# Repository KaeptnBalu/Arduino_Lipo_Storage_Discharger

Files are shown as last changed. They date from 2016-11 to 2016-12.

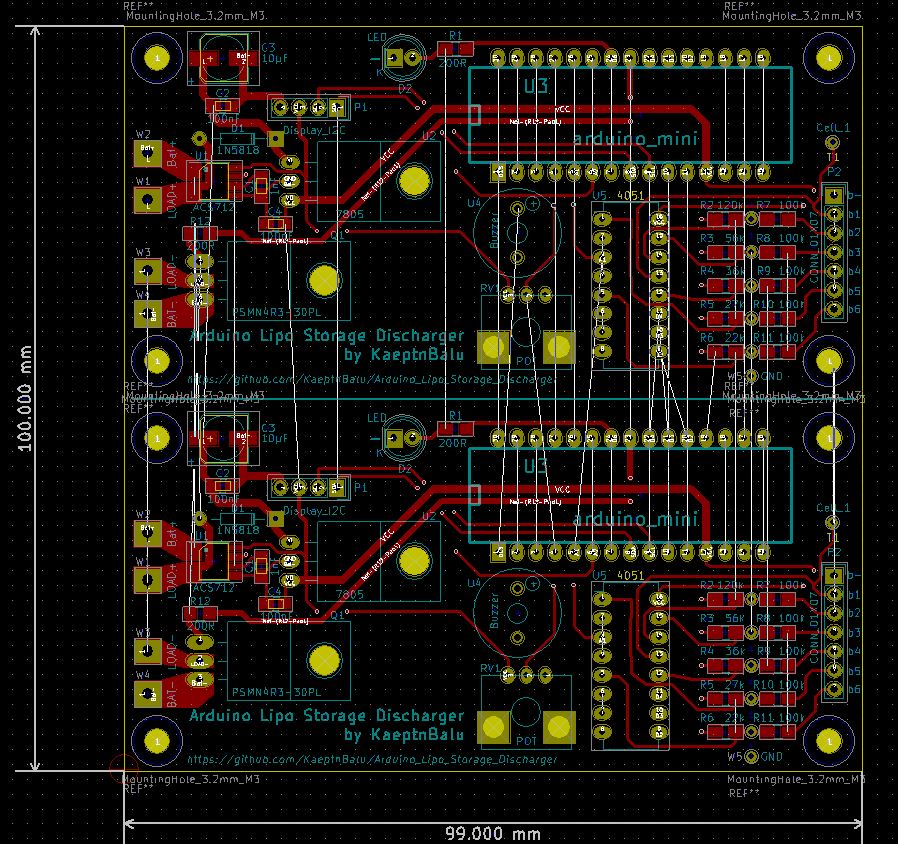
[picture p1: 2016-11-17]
PCB/PCBx2.JPG

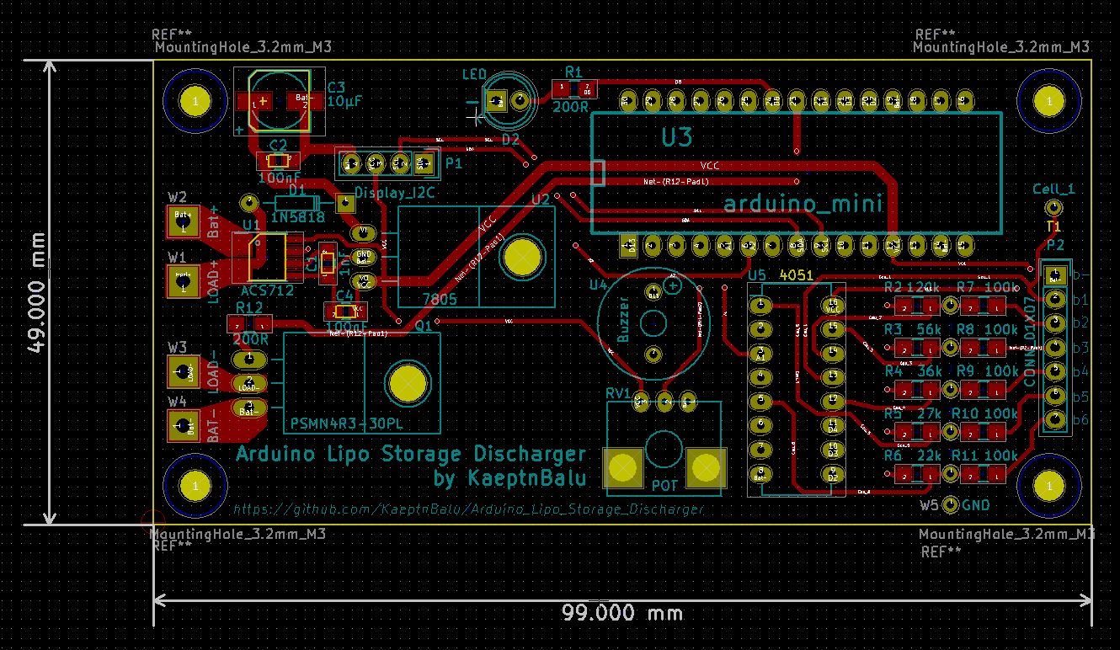
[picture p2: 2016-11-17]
PCB/PCB.JPG

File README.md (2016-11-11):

# Arduino_Lipo_Storage_Discharger
Arduino controlled lipo battery storage discharger with current measurement and current control.

This device can discharge lipo and liion batterys to storage voltage without external power supply.
It can handle 2-6s lipos (8.4 - 25.2V) and can draw up to about 10A continues. 
(Max 140W, with 4 light bulbs)
The current can be controlled by the potentiometer.

The oled display will show: 
- current in A
- battery voltage
- each cell voltage
- total discharged current in mAh
- discharge time

For the discharging load 4 pieces 12V 35w G4 halogen bulbs will be used.
When the storage voltage is reached it will disconnect the load and the buzzer will beep every few seconds.

If you forget to disconnect the Lipo battery after discharging and the voltage drops below 3.75V per cell 
it will go to a low power consumption mode and beep only every few minutes.

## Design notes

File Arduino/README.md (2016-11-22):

Attention: work in progress, code not completely finshed yet

Arduino Code for the Lipo Storage Discharger.

There are external librarys used:
- Ardafruit SSD1306 Library
https://github.com/adafruit/Adafruit_SSD1306
- Ardafruit GFX Library 
https://github.com/adafruit/Adafruit-GFX-Library
- PID Library 
https://github.com/br3ttb/Arduino-PID-Library/

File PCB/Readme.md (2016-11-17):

This is the Arduino Lipo Storage Discharger PCB. It is designed in KICAD.

The project is not finished yet.
So please dont use the files yet to make a board.

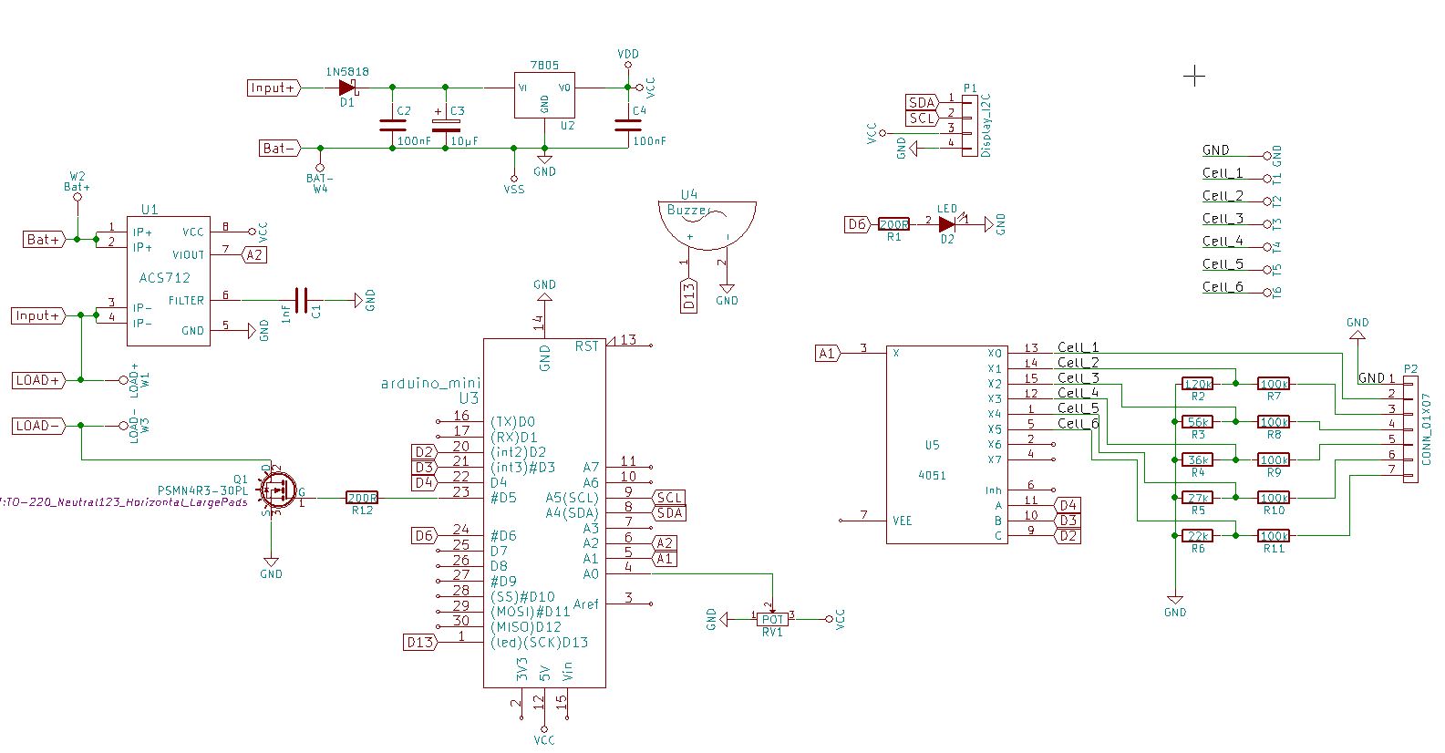
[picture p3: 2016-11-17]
PCB/schematic.JPG

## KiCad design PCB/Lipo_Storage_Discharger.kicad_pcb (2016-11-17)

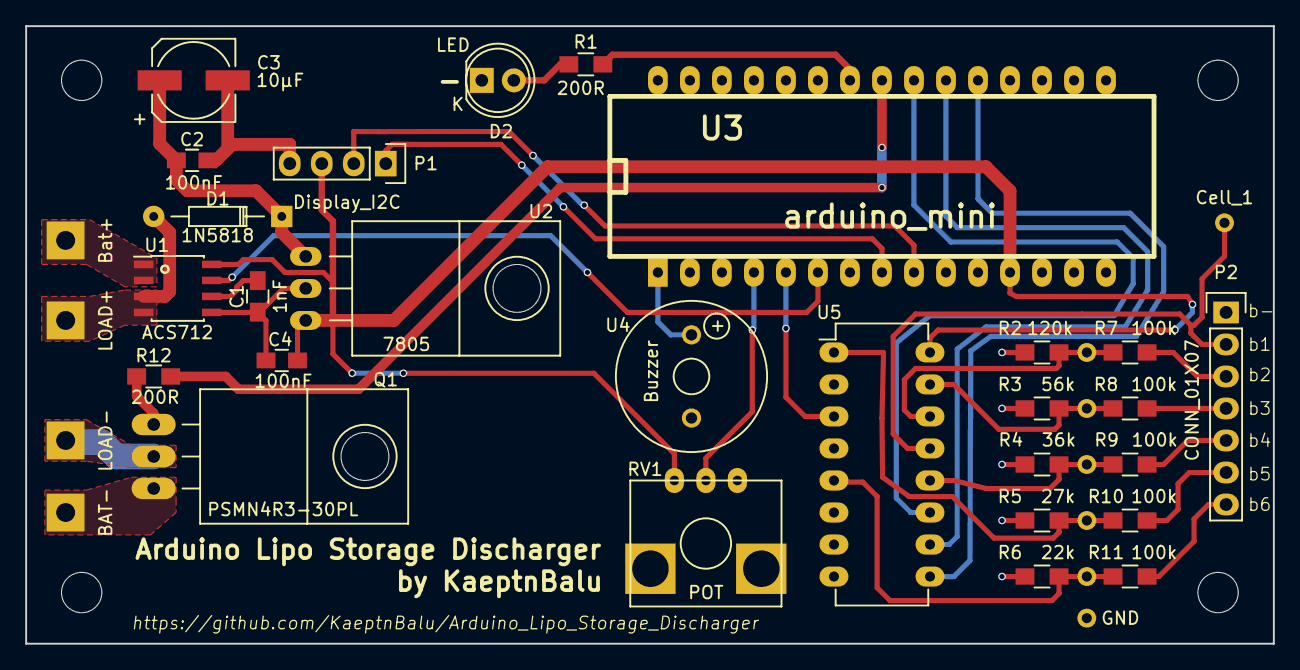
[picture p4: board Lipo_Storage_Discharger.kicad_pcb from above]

Board: 2 copper layers, 99.0 x 49.0 mm, 33 parts (0 on the bottom side), 31 nets.

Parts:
C1: 1nF; C_0805_HandSoldering
C2, C4: 100nF; C_0805_HandSoldering
C3: 10µF; c_elec_6.3x5.3
Cell_1: T1; Measurement_Point_Round-TH_Small
D1: 1N5818; Diode_DO-35_SOD27_Horizontal_RM10
D2: LED; LED-5MM
P1: Display_I2C; Socket_Strip_Straight_1x04
P2: CONN_01X07; Pin_Header_Straight_1x07
Q1: PSMN4R3-30PL; TO-220_Neutral123_Horizontal_LargePads
R1, R12: 200R; R_0805_HandSoldering
R2: 120k; R_0805_HandSoldering
R3: 56k; R_0805_HandSoldering
R4: 36k; R_0805_HandSoldering
R5: 27k; R_0805_HandSoldering
R6: 22k; R_0805_HandSoldering
R7, R8, R9, R10, R11: 100k; R_0805_HandSoldering
RV1: POT; RK09K1130A5R
U1: ACS712; SOIC-8_3.9x4.9mm_Pitch1.27mm
U2: 7805; TO-220_7805_Horizontal
U3: arduino_mini
U4: Buzzer; Buzzer_12x8.2_RM6.6
U5: 4051; DIP-16_W7.62mm_LongPads
W1: LOAD+; Measurement_Point_Square-TH_Big
W2: Bat+; Measurement_Point_Square-TH_Big
W3: LOAD-; Measurement_Point_Square-TH_Big
W4: BAT-; Measurement_Point_Square-TH_Big
W5: GND; Measurement_Point_Round-TH_Small

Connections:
/Cell_1: Cell_1.1, P2.2, U5.13
/Cell_2: R2.1, R7.2, U5.14
/Cell_3: R3.1, R8.2, U5.15
/Cell_4: R4.1, R9.2, U5.12
/Cell_5: R5.1, R10.2, U5.1
/Cell_6: R6.1, R11.2, U5.5
A1: U3.5, U5.3
A2: U1.7, U3.6
Bat+: U1.1, U1.2, W2.1
Bat-: C1.1, C2.2, C3.2, C4.2, D2.1, P1.4, P2.1, Q1.3, R2.2, R3.2, R4.2, R5.2, R6.2, RV1.1, U1.5, U2.GND, U3.14, U3.19, U4.2, U5.8, W4.1, W5.1
D2: U3.20, U5.9
D3: U3.21, U5.10
D4: U3.22, U5.11
D6: R1.2, U3.24
D13: U3.1, U4.1
Input+: D1.2, U1.3, U1.4, W1.1
LOAD-: Q1.2, W3.1
unnamed: C1.2, U1.6
unnamed: C2.1, C3.1, D1.1, U2.VI
unnamed: D2.2, R1.1
unnamed: P2.3, R7.1
unnamed: P2.4, R8.1
unnamed: P2.5, R9.1
unnamed: P2.6, R10.1
unnamed: P2.7, R11.1
unnamed: Q1.1, R12.2
unnamed: R12.1, U3.23
unnamed: RV1.2, U3.4
SCL: P1.2, U3.9
SDA: P1.1, U3.8
VCC: C4.1, P1.3, RV1.3, U1.8, U2.VO, U3.12, U5.16

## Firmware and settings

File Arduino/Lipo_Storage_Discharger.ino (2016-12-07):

// Arduino Lipo Storage Discharger
// Project Page: https://github.com/KaeptnBalu/Arduino_Lipo_Storage_Discharger

#include <Adafruit_GFX.h>       //library for display control
#include <Adafruit_SSD1306.h>   //library for display control
#include <SPI.h>                //library for display I2C communication
#include <Wire.h>

#include <PID_v1.h>  // include the library for PID controller

#define OLED_RESET 4
Adafruit_SSD1306 display(OLED_RESET);

// Input and Output Pin definitions
int MosfetPin = 5;      // Mosfet Pin
int BuzzerPin = 13;     // Buzzer Pin
int LedPin = 6;         // Led Pin
int Mult_CTRL_A = 4;    //4051 Multiplexer select Pin A
int Mult_CTRL_B = 3;    //4051 Multiplexer select Pin B
int Mult_CTRL_C = 2;    //4051 Multiplexer select Pin C
int SDA_Pin = A4;
int SCL_Pin = A5;

int Multiplexer = A1;   //4051 Multiplexer analog signal Pin
int Poti = A0;          //Poti signal Pin
int ACS712 = A2;        //ACS712 Current Sensor analog signal Pin

//------------------------------------------------------------------------------------------------------

//PID variables
//Define Variables we'll be connecting to
double Setpoint, Input, Output;

//Specify the links and initial tuning parameters
PID myPID(&Input, &Output, &Setpoint,2,5,1, DIRECT);


//------------------------------------------------------------------------------------------------------


float Amps = 0.0;                    //Current measured by the ACS712
float cell_storage_voltage = 3.8;    // the storage voltage per cell to which the battery will be discharged 
int discharging = 0;                //discharging status (1: discharging on , 0: discharging off) 
double discharge_power = 0;         //discharge Power in Watts
double max_discharge_power = 120;   //Sets the maximum discharge Power (depending on the load used. example: 4x30Watt light bulb = 120 Watts maximum)
int i=0;
//------------------------------------------------------------------------------------------------------

//Voltage Multiplicators because cell 2 to 6 are read through voltage dividers   (calculation example cell2: (1/(R2/(R2+R7)) )  
// values are measured against ground, so cell 2 has value of cell 1+2, cell3 has value of cell 1+2+3, cell 4 has value of cell 1+2+3+4 ...
float multiplicator1 = 1;  //cell 1 is directly measured, so no multiplicator needed
float multiplicator2 = 1.83333;
float multiplicator3 = 2.78571;
float multiplicator4 = 3.77777;
float multiplicator5 = 4.70370;
float multiplicator6 = 5.54545;

//------------------------------------------------------------------------------------------------------

//variables to control the 4051 multiplexer
int r0 = 0;      //value of select pin at the 4051 (A)
int r1 = 0;      //value of select pin at the 4051 (B)
int r2 = 0;      //value of select pin at the 4051 (C)
int count = 0;   //which X Input pin we are selecting

//variables for the multiplexer output values of cell 1 to 6
float m_cell_1 = 0.0;  
float m_cell_2 = 0.0;
float m_cell_3 = 0.0;
float m_cell_4 = 0.0;
float m_cell_5 = 0.0;
float m_cell_6 = 0.0;

//------------------------------------------------------------------------------------------------------

//variables for the calculated single cell voltages of cell 1 to 6 and total voltage
float v_cell_1 = 0.0;
float v_cell_2 = 0.0;
float v_cell_3 = 0.0;
float v_cell_4 = 0.0;
float v_cell_5 = 0.0;
float v_cell_6 = 0.0;
float v_total = 0.0;

//------------------------------------------------------------------------------------------------------

//variables to calculate the used mAh and Wh
unsigned long msec = 0;
float time = 0.0;
int sample = 0;
float totalCharge = 0.0;
float averageAmps = 0.0;
float ampSeconds = 0.0;
float ampHours = 0.0;
float wattHours = 0.0;


//------------------------------------------------------------------------------------------------------

void setup() {
  // The setup code that runs just once
  
pinMode(MosfetPin,OUTPUT);  // set MosfetPin as Output
pinMode(BuzzerPin,OUTPUT);  // set BuzzerPin as Output
pinMode(LedPin,OUTPUT);  // set LedPin as Output
pinMode(Mult_CTRL_A,OUTPUT);  // set Mult_CTRL_A as Output
pinMode(Mult_CTRL_B,OUTPUT);  // set Mult_CTRL_B as Output
pinMode(Mult_CTRL_C,OUTPUT);  // set Mult_CTRL_C as Output
pinMode(SDA_Pin,OUTPUT);  // set SDA Pin as Output
pinMode(SCL_Pin,OUTPUT);  // set SCL Pin as Output

pinMode(Multiplexer,INPUT);  // set Multiplexer as Input
pinMode(Poti,INPUT);  // set Poti as Input
pinMode(ACS712,INPUT);  // set ACS712 as Input


//initialize the board
display.begin(SSD1306_SWITCHCAPVCC, 0x3C);
display.clearDisplay();

digitalWrite(MosfetPin, LOW);
digitalWrite(LedPin, HIGH);
tone(BuzzerPin, 2000, 500); 
delay(1000);
digitalWrite(LedPin, LOW);

//PID Setup
 //initialize the variables we're linked to
  Input = analogRead(ACS712);
  Setpoint = 1;

  //turn the PID on
  myPID.SetMode(AUTOMATIC);
}

//------------------------------------------------------------------------------------------------------

void loop() {
  // put your main code here, to run repeatedly:

read_cell_voltages();
calculate_single_cell_voltages();
read_amps();
calculate_Ah_and_Wh();


cell_min_voltage_check();           //if all cells are above the storage voltage "discharging" will be set to 1. If not it will be set to 0
if (discharging == 1) PID_loop();
else  analogWrite(MosfetPin,0);


//display_discharge_infos();
//display_cell_voltages();
 display_info_switch();


}


//------------------------------------------------------------------------------------------------------

void PID_loop() {
//PID Loop


Setpoint = (analogRead(Poti)/100);  //creates a poti reading of maximum 10 which means maximum 10 Amps
Input = Amps;  // Input of the PID control gets the actual current flow in A
myPID.Compute();
analogWrite(MosfetPin,Output);  // The Mosfet is controlled by the generated PWM signal

if (discharge_power > max_discharge_power) {
Setpoint = max_discharge_power;  //sets the target of the control loop to the declared max_discharge_power (default: 120 Watts)
Input = discharge_power;  // Input of the PID control gets the actual discharge_power in Watts
myPID.Compute();
analogWrite(MosfetPin,Output);  // The Mosfet is controlled by the generated PWM signal  
}



}

//------------------------------------------------------------------------------------------------------

void read_cell_voltages()  {    
  // The function reads the values from cell 1 to 6 trough the 4051 multiplexer

for (count=0; count<=5; count++) {

 
    // select the bit  

    r0 = bitRead(count,0);    // use this with arduino 0013 (and newer versions)     
    r1 = bitRead(count,1);    // use this with arduino 0013 (and newer versions)     
    r2 = bitRead(count,2);    // use this with arduino 0013 (and newer versions)     


    digitalWrite(Mult_CTRL_A, r0);
    digitalWrite(Mult_CTRL_B, r1);
    digitalWrite(Mult_CTRL_C, r2);

    // read the multiplexed pin here
    switch (count)  {
    case 0:
m_cell_1 = analogRead(Multiplexer);
    break;
    case 1:
m_cell_2 = (analogRead(Multiplexer)*multiplicator2);
    break;
    case 2:
m_cell_3 = (analogRead(Multiplexer)*multiplicator3);
    break;
    case 3:
m_cell_4 = (analogRead(Multiplexer)*multiplicator4);
    break;
    case 4:
m_cell_5 = (analogRead(Multiplexer)*multiplicator5);
    break;
    case 5:
m_cell_6 = (analogRead(Multiplexer)*multiplicator6);
    break;
    }
  
}

}

//------------------------------------------------------------------------------------------------------


void calculate_single_cell_voltages()  {
    //calculate the single cell voltages based on the values read from read_cell_voltages function

if (m_cell_1 < 200) v_cell_1 = 0;
else v_cell_1 = (m_cell_1*(5/1023));

if (m_cell_2 < 200) v_cell_2 = 0;                   //check if the cell is connected. if not,then the voltage value is set to zero
else v_cell_2 = ((m_cell_2 - m_cell_1)*(5/1023));   //if the cell is connected the real voltage is calculated here

if (m_cell_3 < 200) v_cell_3 = 0;
else v_cell_3 = ((m_cell_3 - m_cell_2)*(5/1023));

if (m_cell_4 < 200) v_cell_4 = 0;
else v_cell_4 = ((m_cell_4 - m_cell_3)*(5/1023));

if (m_cell_5 < 200) v_cell_5 = 0;
else v_cell_5 = ((m_cell_5 - m_cell_4)*(5/1023));

if (m_cell_6 < 200) v_cell_6 = 0;
else v_cell_6 = ((m_cell_6 - m_cell_5)*(5/1023));

v_total = (v_cell_1 + v_cell_2 + v_cell_3 + v_cell_4 + v_cell_5 + v_cell_6);  //calculate the total voltage of the connected battery
}

//------------------------------------------------------------------------------------------------------


void read_amps() {
    // read the current that the ACS712 measures

int mVperAmp = 100; // use 100 for 20A Module and 66 for 30A Module
int RawValue= 0;
int ACSoffset = 2500; 
double Voltage = 0;

RawValue = analogRead(ACS712);
Voltage = (RawValue / 1024.0) * 5000; // Gets you mV
Amps = ((Voltage - ACSoffset) / mVperAmp);
discharge_power = (v_total*Amps);
}

//------------------------------------------------------------------------------------------------------

void cell_min_voltage_check() {
    //Function to check all cell voltages are above thg storage voltage (default: 3.8V)

if (v_cell_1 == 0) //messgae: connect balancing cable !


  
if (v_cell_2 != 0)
{
 if ((v_cell_1 > cell_storage_voltage) && (v_cell_2 > cell_storage_voltage))
 discharging = 1;
 else discharging = 0;
}
else //messgae: connect balancing cable !


if (v_cell_3 != 0)
{
 if ((v_cell_1 > cell_storage_voltage) && (v_cell_2 > cell_storage_voltage) && (v_cell_3 > cell_storage_voltage))
 discharging = 1;
 else discharging = 0;
}

if (v_cell_4 != 0)
{
 if ((v_cell_1 > cell_storage_voltage) && (v_cell_2 > cell_storage_voltage) && (v_cell_3 > cell_storage_voltage) && (v_cell_4 > cell_storage_voltage))
 discharging = 1;
 else discharging = 0;
}

if (v_cell_5 != 0)
{
 if ((v_cell_1 > cell_storage_voltage) && (v_cell_2 > cell_storage_voltage) && (v_cell_3 > cell_storage_voltage) && (v_cell_4 > cell_storage_voltage) && (v_cell_5 > cell_storage_voltage))
 discharging = 1;
 else discharging = 0;
}

if (v_cell_6 != 0)
{
 if ((v_cell_1 > cell_storage_voltage) && (v_cell_2 > cell_storage_voltage) && (v_cell_3 > cell_storage_voltage) && (v_cell_4 > cell_storage_voltage) && (v_cell_5 > cell_storage_voltage) && (v_cell_6 > cell_storage_voltage))
 discharging = 1;
 else discharging = 0;
}
  
  
}

//------------------------------------------------------------------------------------------------------

void calculate_Ah_and_Wh() {
      //Function to calculate the used Ah and Wh while discharging  
sample = sample + 1;
msec = millis();
time = (float) msec / 1000.0;

totalCharge = totalCharge + Amps;
averageAmps = totalCharge / sample;
ampSeconds = averageAmps*time;
ampHours = ampSeconds/3600;
wattHours = v_total * ampHours;  
}

//------------------------------------------------------------------------------------------------------

void display_discharge_infos()
{
  display.setTextSize(1);
  display.setTextColor(WHITE);
  display.clearDisplay();

  display.setCursor(0,0);
  display.println("Battery Voltage:");
  display.setCursor(0,10);
  display.println(v_total);
  display.setCursor(40,10);
  display.println("V");

display.drawFastHLine(0,19,125,WHITE);

  display.setCursor(0,22);
  display.println("Dis Current + Power:");
  display.setCursor(0,32);
  display.println(Amps);
  display.setCursor(40,32);
  display.println("A");
  display.setCursor(65,32);
  display.println(discharge_power);
  display.setCursor(105,32);
  display.println("W");
  
display.drawFastHLine(0,41,125,WHITE);

  display.setCursor(0,44);
  display.println("Used Ah and Wh:");
  display.setCursor(0,54);
  display.println(ampHours);
  display.setCursor(40,54);
  display.println("Ah");
  display.setCursor(65,54);
  display.println(wattHours);
  display.setCursor(105,54);
  display.println("Wh");
  
  display.display();
}  

void display_cell_voltages()
{
  display.setTextSize(1);
  display.setTextColor(WHITE);
  display.clearDisplay();

  display.setCursor(10,0);
  display.println("Cell 1:");
  display.setCursor(60,0);
  display.println(v_cell_1);

  display.setCursor(10,10);
  display.println("Cell 2:");
  display.setCursor(60,10);
  display.println(v_cell_2);

  display.setCursor(10,20);
  display.println("Cell 3:");
  display.setCursor(60,20);
  display.println(v_cell_3);

  display.setCursor(10,30);
  display.println("Cell 4:");
  display.setCursor(60,30);
  display.println(v_cell_4);

  display.setCursor(10,40);
  display.println("Cell 5:");
  display.setCursor(60,40);
  display.println(v_cell_5);

  display.setCursor(10,50);
  display.println("Cell 6:");
  display.setCursor(60,50);
  display.println(v_cell_6);

  display.display();
 }

void display_info_switch()
{

  i = i+1;
  if (i<100) display_discharge_infos();
  else display_cell_voltages();
  
  if (i>140) i=0;
  
  
  }
